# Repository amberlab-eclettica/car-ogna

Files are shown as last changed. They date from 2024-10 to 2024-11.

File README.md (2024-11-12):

# Project car-ogna
### Amberlab - 2024

This project involves creating a Raspberry Pi-controlled RC car, built for First-Person View (FPV) driving. The car is controlled through a web browser, using either the arrow keys on your PC keyboard or (coming soon) a joystick for enhanced control.
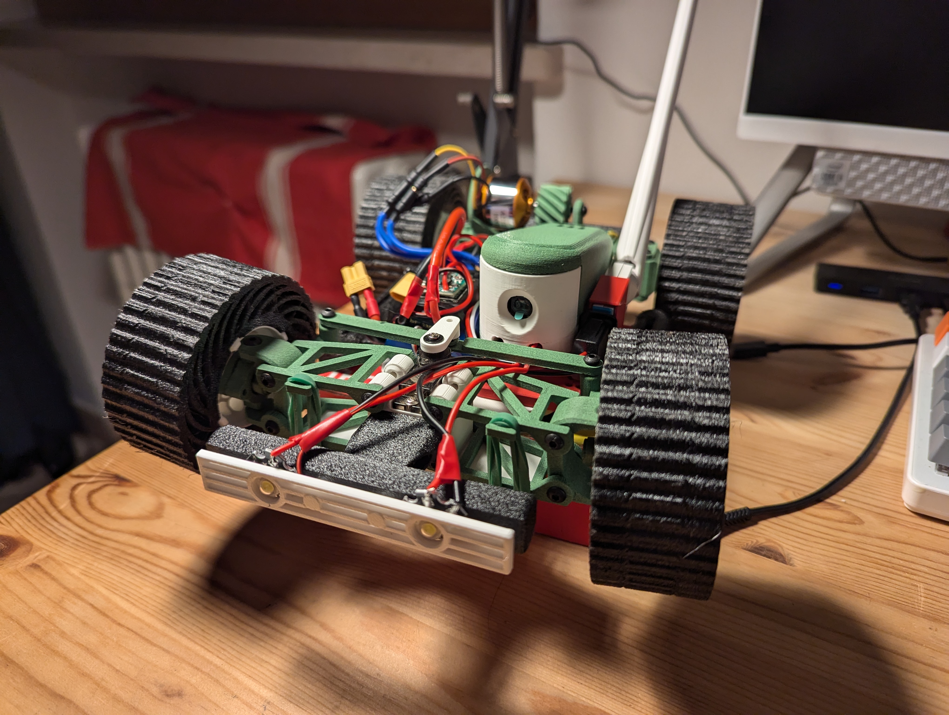
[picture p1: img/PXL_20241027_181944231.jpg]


### Electronics and Hardware

The main components include a Raspberry Pi Zero 2 for central control, paired with a brushless motor A2212 and Electronic Speed Controller (ESC) to serve as the car’s engine, and a micro servo motor for steering.

### FPV Vision

For FPV vision, the car is equipped with a Raspberry Pi camera and a USB WiFi adapter (using the Tenda U2, though any compatible adapter can work) or the Pi’s built-in WiFi. 

### Chassis
The car’s chassis is based on the <a href="https://www.thingiverse.com/thing:4233353">Carduino V2</a> with minor adjustments and includes a modified case <a href="https://www.thingiverse.com/thing:1639568"> Pi Zero camera housing</a>, and <a href="https://makerworld.com/it/models/212433?from=search">custom wheels</a>. Everything can be 99% 3D printed, as the only non printed components are M3 screws and four bearrings.

### Power System

Power is provided by 2S Li-ion batteries with a USB-C charging port built into the car for easy recharging, and a Battery Elimination Circuit (BEC) regulates power for the Raspberry Pi. The car also features bright LED headlights at the front and a red LED at the back for visibility.

## Assembling the car

Work in progress.

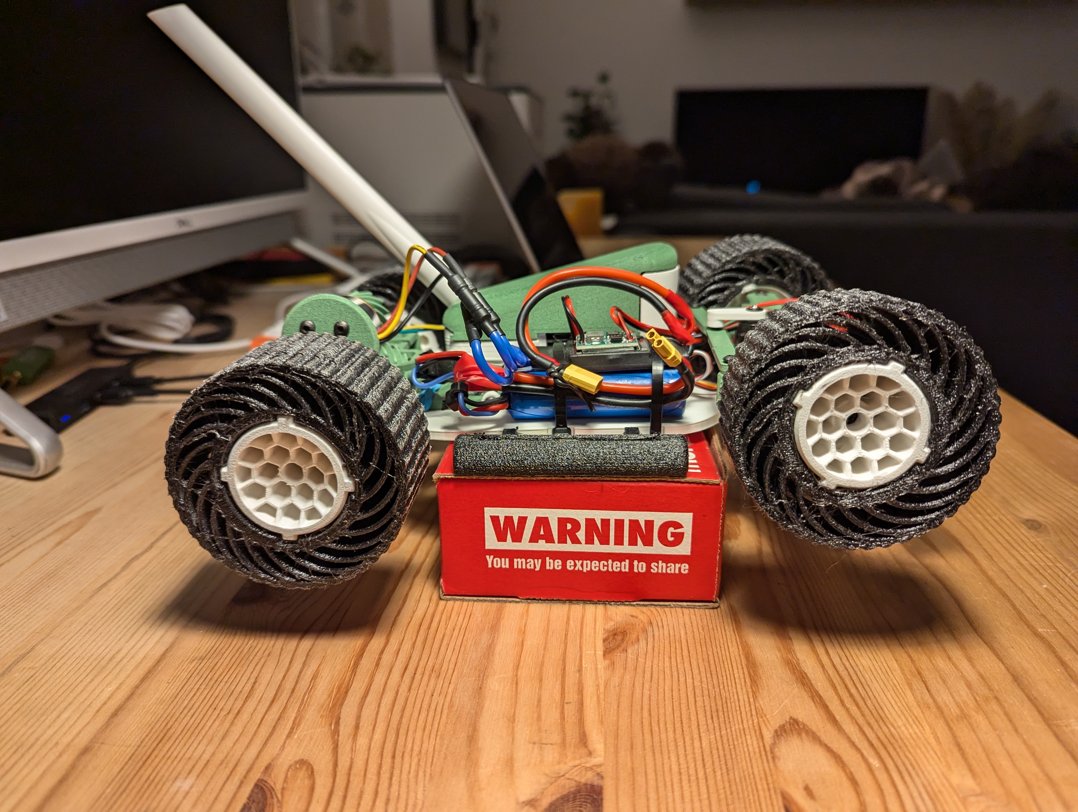
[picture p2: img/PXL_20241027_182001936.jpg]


## Setup of the Raspberry
Once all hardware components are mounted and connected, flash the Raspberry Pi OS onto your SD card, power on the Raspberry Pi, and [SSH into the device](https://www.raspberrypi.com/documentation/computers/remote-access.html#ssh). It is preferrable to use the headless version of Raspbian, as it is lighter and allows a faster stream.

### Step 1: Initial Setup and Updates

After connecting via SSH, run the following commands to ensure the system is updated and upgraded, and install the necessary packages, namely picamera2 and git.

    sudo apt update
    sudo apt upgrade -y
    sudo apt install -y git python3-picamera2 --no-install-recommends

The full update and installation can take a while.

## Step 2: Configure gpiod and Clone the Project Repository

First, ensure `gpiod` starts automatically with the system. Run the following command to enable it:

    sudo systemctl enable pigpiod

Next, clone the Git repository for the car-ogna project to your Raspberry Pi, and reboot the Raspberry for all changes to take effect:

    git clone https://github.com/amberlab-eclettica/car-ogna.git
    sudo reboot

## Step 3: Install USB WiFi Adapter Drivers

For those using USB WiFi adapters, navigate into the project folder:

    cd car-ogna

Then, install the drivers for the USB adapter with the following command:

    sudo dpkg -i driver/AX300-WiFi-Adapter-Linux-Driver-arm.deb
    sudo reboot
    
also this might take some time, reboot at the end.

## Step 4: Launch and Autostart the Interface

To check that everything is working correctly, launch the interface with the following command:

    python interface.py
    
If everything goes well, the server should start, and you will see two columns of numbers on the screen displaying the speed and steering commands of the car, respectively.
To view the FPV stream and control the car, using a web browser navigate to:

    YOURCARNAME.local:8000
    YOURCARIP:8000
    
Once there, you can click on the commands or press the keys on your keyboard to check that the car responds as expected.
If all works well move to step 5, otherwise it's troubleshooting time.

## Step 5: Autostart the Interface

To autostart the interface, you need to create a service file named `interface.service`. Use a text editor to create and edit the file:

    sudo nano /etc/systemd/system/interface.service

Then, add the following content to the file:
    
    [Unit]
    Description=Interface for RC car control
    After=network.target
    
    [Service]
    ExecStart=/usr/bin/python3 /home/USERNAME/car-ogna/interface.py
    WorkingDirectory=/home/USERNAME/car-ogna/
    StandardOutput=inherit
    StandardError=inherit
    Restart=always
    User=USERNAME
    
    [Install]
    WantedBy=multi-user.target

Save the file (CTRL-O) and exit the editor (CTRL-X).

Finally, enable and start the service with the following commands:

    sudo systemctl enable interface.service
    sudo systemctl start interface.service

## Step 5: Set Up a WiFi Hotspot

First, check which WiFi interface your device is using (for example, `wlan1`) with the following command:

    nmcli device

Next, start a hotspot using the following commands:
    
    sudo nmcli con add type wifi ifname wlan1 con-name carogna-hotspot autoconnect yes ssid carogna-hotspot
    sudo nmcli con modify carogna-hotspot 802-11-wireless.mode ap 802-11-wireless.band bg ipv4.method shared
    sudo nmcli con modify carogna-hotspot wifi-sec.key-mgmt wpa-psk
    sudo nmcli con modify carogna-hotspot wifi-sec.psk "PASSWORD"
    sudo nmcli con up carogna-hotspot

This will create a hotspot named "carogna-hotspot" with the specified password "PASSWORD".

## Step 6: Allow server restarting with no password
This is relevant if, after modifying some of the car configuration parameters, you want to restart the server instead of rebooting the car.

Open the sudoers file using the visudo command. This will prevent syntax errors that could lock you out of sudo privileges.
        
    sudo visudo
        
In the sudoers file, add a line at the end of the file (or in the appropriate section) that allows the user to restart the service without needing a password.

The syntax to allow a user to run the systemctl restart command for a specific service without a password is:

    username ALL=NOPASSWD: /bin/systemctl restart interface.service

Replace username with the actual username that you want to grant this privilege to.

After adding the rule, save and exit the editor:
If you're using visudo, press Ctrl + X to exit, then press Y to confirm changes, and Enter to save.

Test the configuration: After editing the sudoers file, try running the following command as the specified user:

    sudo systemctl restart interface.service

The service should restart without asking for a password.
This will grant the specified user permission to restart interface.service without requiring sudo passwords.

## Final Remarks

Now you can use your car either by connecting it to an existing network or using the WiFi hotspot. Reboot the car one last time and verify that both the interface and the hotspot are autostarting correctly.

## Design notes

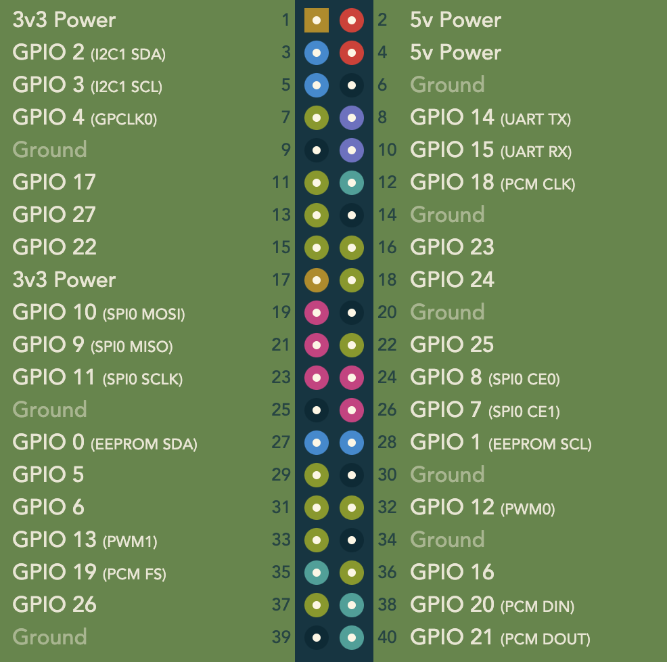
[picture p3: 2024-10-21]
docs/rpi_zero_pinout.png

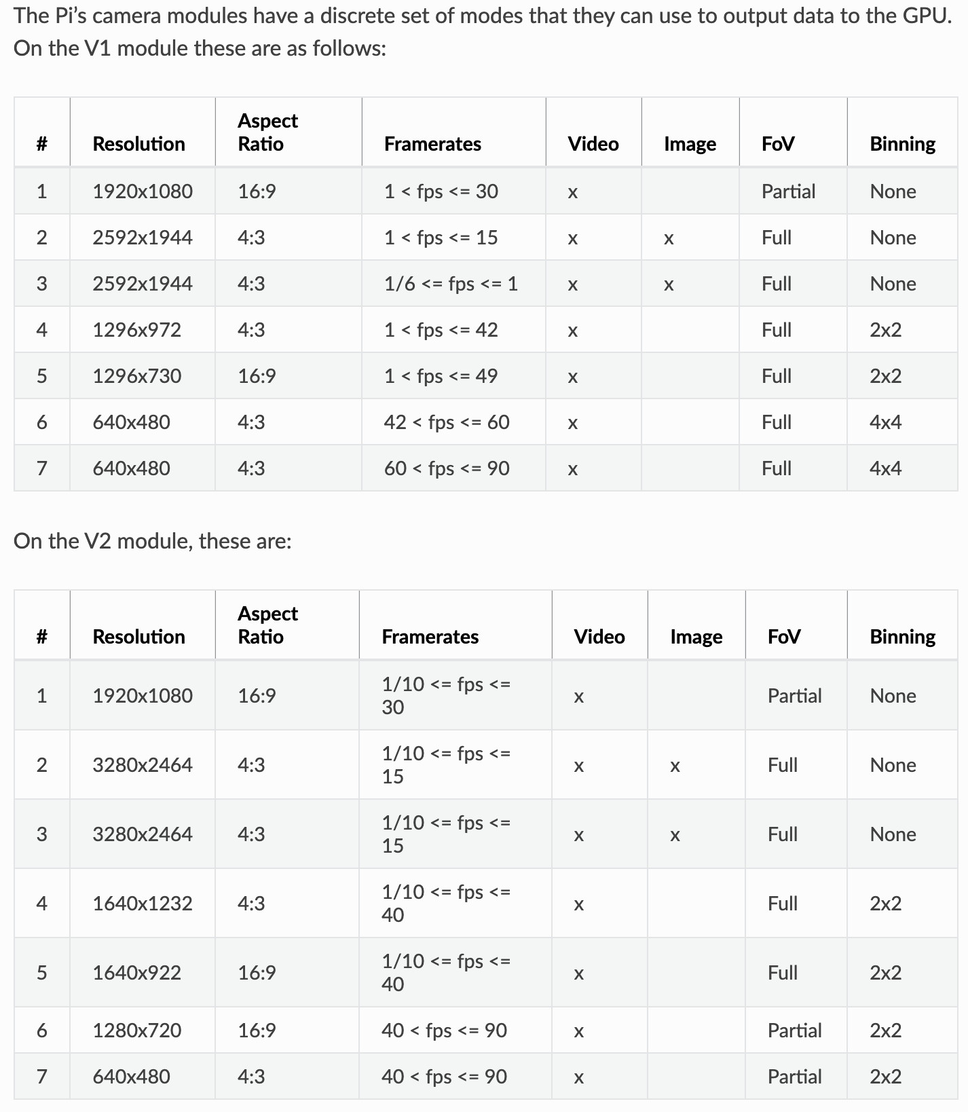
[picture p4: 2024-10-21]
docs/camera_resolution.png

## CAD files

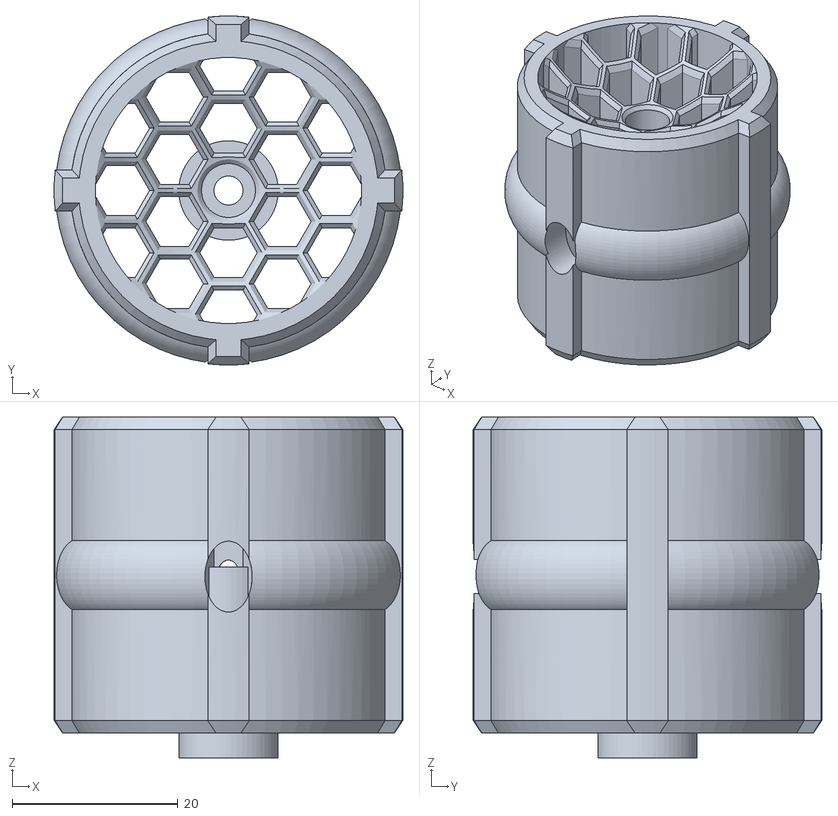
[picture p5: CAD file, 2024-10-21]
3D/rua_drio - hub.stl
42.1 x 42.1 x 41.1

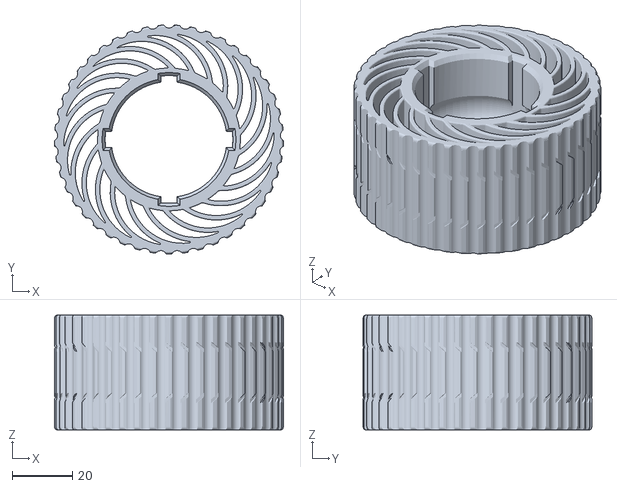
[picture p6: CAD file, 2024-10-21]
3D/rua_drio - Tire.stl
76.2 x 76.2 x 38.1

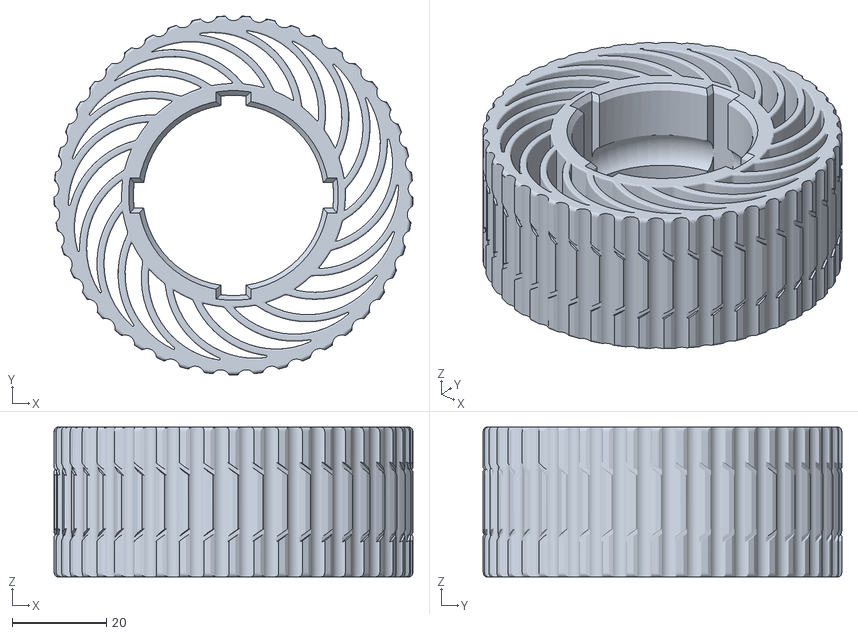
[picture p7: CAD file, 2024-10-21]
3D/rua_denansi - Tire.stl
76.2 x 76.2 x 31.8

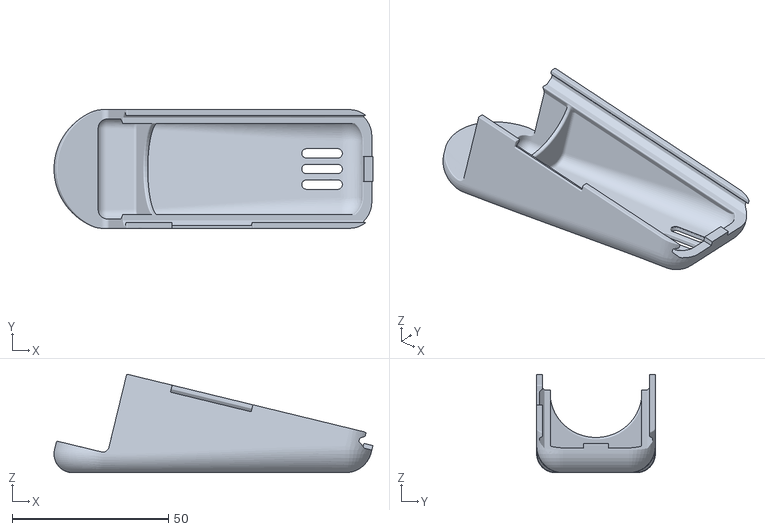
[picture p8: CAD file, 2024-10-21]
3D/PiZeroCamCaseTop.stl
102.1 x 38.0 x 31.5

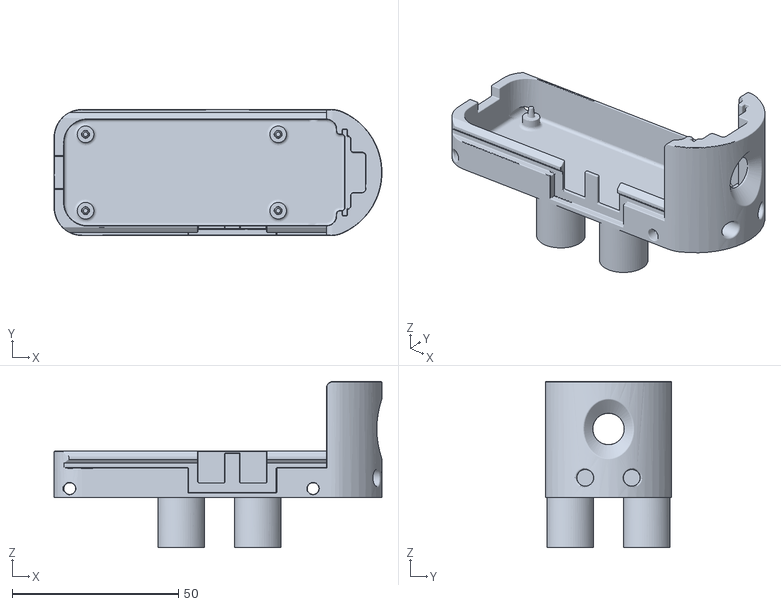
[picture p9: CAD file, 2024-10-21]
3D/PiZeroCamCaseBase.stl
98.8 x 38.0 x 50.0

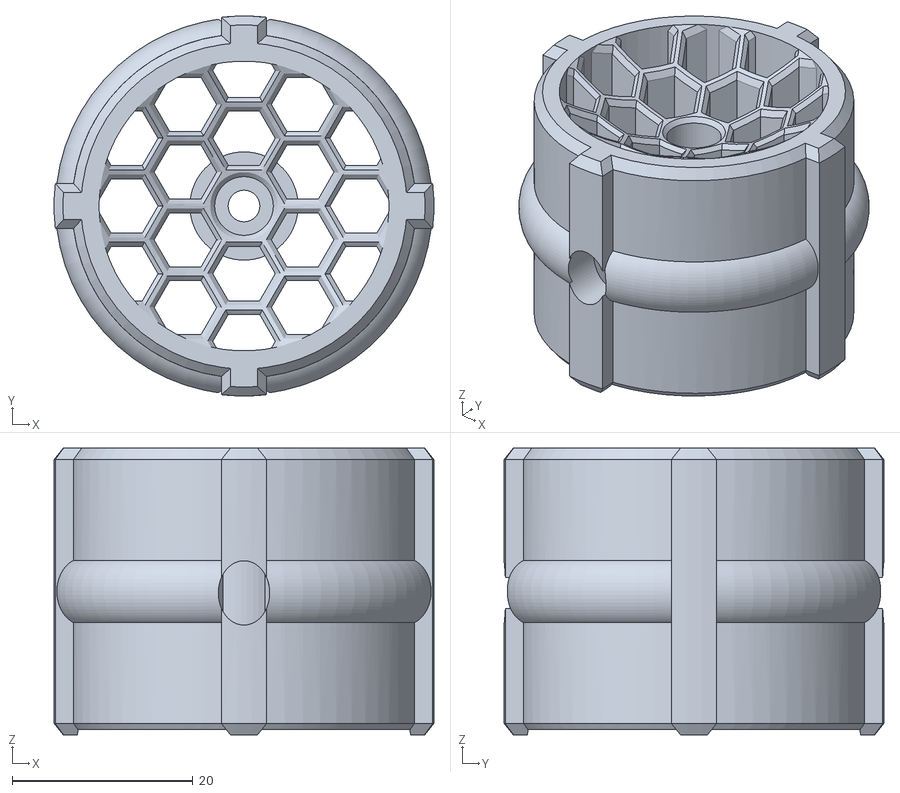
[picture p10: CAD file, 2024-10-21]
3D/rua_denansi - hub.stl
42.1 x 42.1 x 31.8

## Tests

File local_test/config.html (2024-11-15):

# car-ogna configuration

ESC Pin (18):

ESC Frequency (50):

Servo Pin (23):

Min Speed (0):

Max Speed (30):

Acceleration function (x):

Zero Angle (0):

Steering Step (25):

Max Angle (50):

Min Angle (-50):

Pin Fanale 1 (27):

Pin Fanale 2 (22):

Pin Fanale Retro (17):

Acceleration (4):

Deceleration (4):

Resolution (640x480):

Enable Video Queue (false):

Video Buffer (2):

Save Configuration Reload Server

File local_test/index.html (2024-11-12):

# Interface 0.5

Stream Image

Caveve Green Start recording Stop recording

↑

←

↓

→

carogna2.local:8000

Configuration

### Recorded Videos

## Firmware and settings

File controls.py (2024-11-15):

import time
import os
from gpiozero import PWMOutputDevice, AngularServo, LED
from gpiozero.pins.pigpio import PiGPIOFactory

from picamera2.encoders import MJPEGEncoder, H264Encoder
from picamera2.outputs import FileOutput

import numpy as np
import json

# Set the pin factory to use pigpio
factory = PiGPIOFactory()

# Load configuration from JSON file
with open('config.json', 'r') as config_file:
    config = json.load(config_file)

def string_to_function(expression):
    """
    Converts a string representing a mathematical expression into a Python function that takes variables.
    
    Parameters:
    expression (str): The mathematical expression as a string.
    
    Returns:
    function: A function that evaluates the expression for given variables.
    """
    def generated_function(**kwargs):
        # Pass kwargs as the local dictionary for variable substitution
        return eval(expression, {"np": np}, kwargs)
    
    return generated_function

class MotorController:
    def __init__(self):
        # Load configuration values from JSON
        self.ESC_PIN = config["ESC_PIN"]  # GPIO pin for the ESC signal
        self.ESC_FREQUENCY = config["ESC_FREQUENCY"] # Works at 50 Hz
        self.SERVO_PIN = config["SERVO_PIN"]  # GPIO pin for the servo

        # ESC options
        self.MIN_SPEED = config["MIN_SPEED"]
        self.MAX_SPEED = config["MAX_SPEED"]
        self.ACCELERATION_FUNCTION = config["ACCELERATION_FUNCTION"]

        # Servo options
        self.ZERO_ANGLE = config["ZERO_ANGLE"]
        self.STEERING_STEP = config["STEERING_STEP"] # needs to be multiple of max and min angle
        self.MAX_ANGLE = config["MAX_ANGLE"]
        self.MIN_ANGLE = config["MIN_ANGLE"]

        # Set up PWM for ESC using gpiozero
        self.pwm_esc = PWMOutputDevice(self.ESC_PIN, pin_factory=factory, frequency=self.ESC_FREQUENCY)
        # Set up AngularServo for steering with min/max pulse widths
        self.servo = AngularServo(self.SERVO_PIN, min_angle=self.MIN_ANGLE, max_angle=self.MAX_ANGLE, pin_factory=factory)

        # Start PWM signals
        self.set_speed(0)  # ESC starts at 0% speed
        self.steer(self.ZERO_ANGLE)  # Servo starts at zero angle

    def calibrate_esc(self):
        """Calibrate ESC to recognize throttle range."""
        print("Calibrating ESC...")
        self.pwm_esc.value = 0.1  # Full throttle (10%)
        time.sleep(2)
        self.pwm_esc.value = 0.05  # Zero throttle (neutral position)
        time.sleep(2)
        print("Calibration complete.")

    def speed_function(self, x):
        """Define time vs. speed increase function"""
        function = string_to_function(self.ACCELERATION_FUNCTION)
        return function(x=x)

    def set_speed(self, speed):
        """Set the speed of the brushless motor (0-100%)."""
        self.pwm_esc.value = 0.05 + (self.speed_function(speed) / 2000)  # the ESC uses a 0.5 - 0.1 scale for PWM

    def steer(self, angle):
        """Set the steering angle for the servo motor."""
        self.servo.angle = angle  # Set the angle for the AngularServo

    def cleanup(self):
        """Clean up and stop PWM signals."""
        self.pwm_esc.off()
        self.servo.detach()


class LightController:
    def __init__(self):
        # Load configuration values from JSON
        self.PIN_FANALE_1 = config["PIN_FANALE_1"]
        self.PIN_FANALE_2 = config["PIN_FANALE_2"]
        self.PIN_FANALE_RETRO = config["PIN_FANALE_RETRO"]

        # Set up LEDs using gpiozero
        self.fanale_1 = LED(self.PIN_FANALE_1, pin_factory=factory)
        self.fanale_2 = LED(self.PIN_FANALE_2, pin_factory=factory)
        self.fanale_retro = LED(self.PIN_FANALE_RETRO, pin_factory=factory)

    def toggle_fanale_1(self):
        """Toggle the first light (fanale_1) on or off."""
        self.fanale_1.toggle()

    def toggle_fanale_2(self):
        """Toggle the second light (fanale_2) on or off."""
        self.fanale_2.toggle()

    def toggle_fanale_retro(self):
        """Toggle the rear light (fanale_retro) on or off."""
        self.fanale_retro.toggle()

class CameraController:
    def __init__(self, camera, output_directory):
        self.camera = camera
        self.recording = False
        self.output_directory = output_directory
        os.makedirs(self.output_directory, exist_ok=True)
        self.video_path = None  # To hold the path of the current video

    def start_recording(self):
        if not self.recording:
            # Create an encoder and path for recording
            encoder = H264Encoder()
            self.video_path = os.path.join(self.output_directory, "video_" + time.strftime("%Y%m%d_%H%M%S") + ".h264")
            self.camera.start_recording(encoder, FileOutput(self.video_path))
            self.recording = True
            print(f"Started recording: {self.video_path}")

    def stop_recording(self):
        if self.recording:
            self.camera.stop_recording()  # Stop only the recording
            self.recording = False
            print("Stopped recording")

if __name__ == "__main__":
    motor_controller = MotorController()
    light_controller = LightController()
    
    try:
        # Example usage
        motor_controller.set_speed(motor_controller.MAX_SPEED/3)  # Move forward at 30% speed
        motor_controller.steer(motor_controller.MAX_ANGLE-10)  # Turn left

        # Toggle lights individually
        light_controller.toggle_fanale_1()  # Toggle fanale_1
        light_controller.toggle_fanale_2()  # Toggle fanale_2
        light_controller.toggle_fanale_retro()  # Toggle fanale_retro

        print('Setting motor to 0.1 and steering left.')
        time.sleep(1)

        motor_controller.steer(0)  # Turn back at 0 degrees
        light_controller.toggle_fanale_1()  # Toggle fanale_1
        light_controller.toggle_fanale_2()  # Toggle fanale_2
        light_controller.toggle_fanale_retro()  # Toggle fanale_retro
        time.sleep(1)
    finally:
        motor_controller.cleanup()  # Ensure cleanup on exit

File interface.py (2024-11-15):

#!/usr/bin/python3

import os
import io
import time
import logging
import socketserver
import threading
from http import server
import subprocess

import json

from picamera2 import Picamera2
from picamera2.encoders import MJPEGEncoder
from picamera2.outputs import FileOutput

# Load configuration from JSON file
with open('config.json', 'r') as config_file:
    config = json.load(config_file)

# Import the controllers
from controls import MotorController, LightController, CameraController

# Create an instance of MotorController
motor_controller = MotorController()
light_controller = LightController()

# Get all the relevant numbers from controls
# ESC
MIN_SPEED = motor_controller.MIN_SPEED
MAX_SPEED = motor_controller.MAX_SPEED
# Servo
ZERO_ANGLE = motor_controller.ZERO_ANGLE 
STEERING_STEP = motor_controller.STEERING_STEP
MAX_ANGLE = motor_controller.MAX_ANGLE
MIN_ANGLE = motor_controller.MIN_ANGLE

# Increments which control the acceleration
ACCELERATION = config["ACCELERATION"]
DECELERATION = config["DECELERATION"]

# Streamin settings
VIDEO_RESOLUTION_X = config["VIDEO_RESOLUTION_X"]
VIDEO_RESOLUTION_Y = config["VIDEO_RESOLUTION_Y"]
VIDEO_QUEUE = config["VIDEO_QUEUE"]
VIDEO_BUFFER = config["VIDEO_BUFFER"]

# Video save folder
VIDEO_DIRECTORY = os.path.join("videos")

# Read the HTML interface from the file index.html
with open("index.html") as page_html:
    PAGE = page_html.read()

# State Variables
current_speed = 0  # Motor speed (0-100%)
current_steering_angle = ZERO_ANGLE  # Steering angle (0 = left, 90 = straight, 180 = right)

# **Updated State Variables**
keysPressed = {
    "ArrowUp": False,
    "ArrowDown": False,
    "ArrowLeft": False,
    "ArrowRight": False
}

# Lock for thread-safe state updates
state_lock = threading.Lock()

class StreamingOutput(io.BufferedIOBase):
    def __init__(self):
        self.frame = None
        self.condition = threading.Condition()

    def write(self, buf):
        with self.condition:
            self.frame = buf
            self.condition.notify_all()

class StreamingHandler(server.BaseHTTPRequestHandler):
    def do_GET(self):
        global is_accelerating, is_braking, is_turning_left, is_turning_right
        if self.path == "/":
            self.send_response(301)
            self.send_header("Location", "/index.html")
            self.end_headers()

        elif self.path == "/config.html":
            try:
                # Set the path to your HTML file
                with open("config.html", "rb") as config_file:
                    content = config_file.read()
                    self.send_response(200)
                    self.send_header("Content-Type", "text/html")
                    self.send_header("Content-Length", len(content))
                    self.end_headers()
                    self.wfile.write(content)
            except FileNotFoundError:
                self.send_error(404, "Configuration page not found.")

        elif self.path == "/index.html":
            content = PAGE.encode("utf-8")
            self.send_response(200)
            self.send_header("Content-Type", "text/html")
            self.send_header("Content-Length", len(content))
            self.end_headers()
            self.wfile.write(content)

        elif self.path == "/stream.mjpg":
            self.send_response(200)
            self.send_header("Age", 0)
            self.send_header("Cache-Control", "no-cache, private")
            self.send_header("Pragma", "no-cache")
            self.send_header(
                "Content-Type", "multipart/x-mixed-replace; boundary=FRAME"
            )
            self.end_headers()
            try:
                while True:
                    with output.condition:
                        output.condition.wait()
                        frame = output.frame
                    self.wfile.write(b"--FRAME\r\n")
                    self.send_header("Content-Type", "image/jpeg")
                    self.send_header("Content-Length", len(frame))
                    self.end_headers()
                    self.wfile.write(frame)
                    self.wfile.write(b"\r\n")
            except Exception as e:
                logging.warning(
                    "Removed streaming client %s: %s", self.client_address, str(e)
                )

        elif self.path == "/videos":
            # List all items in the videos directory
            items = os.listdir(VIDEO_DIRECTORY)
            # Filter only video files (you can adjust the extension as needed)
            videos = [item for item in items if item.endswith(('.mjpeg', '.h264'))]

            # Send JSON response
            self.send_response(200)
            self.send_header("Content-Type", "application/json")
            self.end_headers()
            self.wfile.write(json.dumps({'videos': videos}).encode("utf-8"))


        elif self.path.startswith("/videos/"):
            video_file_name = self.path.split("/")[-1]
            video_file_path = os.path.join(VIDEO_DIRECTORY, video_file_name)

            print(f"Requested video file path: {video_file_path}")  # Debugging line

            if os.path.exists(video_file_path):
                self.send_response(200)
                self.send_header("Content-Type", "application/octet-stream")
                self.send_header("Content-Disposition", f"attachment; filename={video_file_name}")
                self.end_headers()

                with open(video_file_path, "rb") as video_file:
                    self.wfile.write(video_file.read())
            else:
                self.send_error(404, "Video not found")

        elif self.path == "/toggle_switch_1":
            # Handle request to toggle the LED
            self.send_response(200)
            self.send_header("Content-Type", "text/plain")
            self.end_headers()
            # Toggle the PIN_FANALE_1 state
            light_controller.toggle_fanale_1()

        elif self.path == "/toggle_switch_2":
            # Handle request to toggle the LED
            self.send_response(200)
            self.send_header("Content-Type", "text/plain")
            self.end_headers()
            # Toggle the PIN_FANALE_2 state
            light_controller.toggle_fanale_2()

        elif self.path == "/toggle_switch_3":
            # Handle request to toggle the LED or perform another action
            self.send_response(200)
            self.send_header("Content-Type", "text/plain")
            self.end_headers()
            # Toggle whatever functionality you intend
            light_controller.toggle_fanale_retro()
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

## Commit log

2024-10-21 First commit
    Adding all the code and the modified stl files.
    [PiZeroCamCaseBase.stl, PiZeroCamCaseTop.stl, rua_denansi - Tire.stl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]
2024-10-24 Added image of the prototype.
2024-10-25 Add driver for Tenda U2
    Added a new folder which contains a working raspberry pi driver for the Tenda U2 WiFi adapter.
2024-10-31 GPIO update
    Switched a couple of GPIOs
2024-11-12 Update to add config file
    First try to add the config file, plus minor fixes in the main code. Still to be tested.
    [controls.py, interface.py]
